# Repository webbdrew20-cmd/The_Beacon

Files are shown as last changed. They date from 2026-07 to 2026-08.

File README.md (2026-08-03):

# 📡 Project Beacon

> **An air-gapped, ultra-low-power emergency information server, long-range LoRa mesh communicator, and local weather station.**

---

## 💡 Why Project Beacon Was Built

In severe weather events, natural disasters, or power grid failures, centralized telecommunications are usually the first point of failure. When cell towers lose power and internet service drops, two vital lifelines disappear instantly: **access to information** (medical emergency guides, survival handbooks, repair manuals) and **the ability to communicate** with neighbors and loved ones.

**Project Beacon** was created to solve this problem by bringing both lifelines into a single, compact, off-grid appliance. Operating entirely on standard 5V USB power banks or small solar panels, Beacon creates an instant local Wi-Fi portal and long-range radio network—requiring **zero cellular service, zero internet connections, and zero external infrastructure.**

---

## 🎯 Target Use Cases & Scenarios

* 🌪️ **Natural Disasters & Severe Weather:** Deploy during hurricanes, tornadoes, floods, or winter storms when local cell towers suffer blackouts or tower congestion.
* 📻 **Emergency Community Mesh Communications:** Establish decentralized, long-range text messaging across miles between neighborhood nodes without relying on third-party cellular carriers or ISPs.
* 🏕️ **Off-Grid & Backcountry Expeditions:** Provide hikers, overlanders, or off-grid homesteads with offline maps, survival literature, and micro-climate forecasting where cell service doesn't exist.
* 🏥 **Offline Medical & Survival Reference Hub:** Host complete offline copies of Wikipedia, emergency medical guides, and technical manuals accessible from any smartphone, tablet, or laptop via a local captive Wi-Fi portal.

---

## 🚀 Motivation & Mission

I undertook this project to build a fully open-source, modular hardware appliance that proves what modern low-power microcontrollers are truly capable of. 

Rather than relying on expensive, power-hungry single-board computers or proprietary commercial gear, Project Beacon combines the high-compute RISC-V architecture of the **ESP32-P4** with specialized **ESP32-S3** auxiliary microcontrollers. By dividing the workload—allocating heavy ZIM database search indexing to the main P4 board, LoRa packet routing to a dedicated radio node, local media streaming to a secondary S3, and micro-climate barometric analysis to a compact sensor node—the system achieves high performance while pulling minimal power.

This repository contains everything needed to build your own Beacon node from scratch: open-source C++/ESP-IDF firmware, pin-by-pin hardware schematics, 3D-printable enclosure files (`.3mf`), and step-by-step flashing guides.

# The_Beacon
Low-power, 5V ESP32 off-grid survival appliance featuring 256GB offline Wikipedia, LoRa mesh messaging, and environmental weather sensing.
## 📦 Bill of Materials (BOM)

Project Beacon relies on a modular, multi-controller architecture to handle heavy offline data processing, long-range mesh networking, and environmental monitoring without internet access.

### 🧠 Processing & Controllers
| Component | Model / Variant | Qty | Function in Project Beacon |
| :--- | :--- | :---: | :--- |
| **Main Processing Node** | Waveshare ESP32-P4 Wi-Fi 6 Basic Kit | 1 | Primary server host (High-performance RISC-V compute, web hosting, offline database indexing) |
| **Entertainment** | ESP32-S3-WROOM-2 | 1 | Dedicated controller managing communication pipelines and local display UI |
|**Weather/Lora Nodes** | ESP32-S3 Super Mini | 2 | Ultra-compact controllers for remote sensor gathering and auxiliary radio endpoints |

### 💾 Storage & Data
| Component | Model / Variant | Qty | Function in Project Beacon |
| :--- | :--- | :---: | :--- |
| **MicroSD Module** | HW-125 SD Card Reader | 2 | SPI-based storage interface for hosting large offline ZIM databases (Wikipedia/Medical) and system logs |

### 📡 Wireless & Communication
| Component | Model / Variant | Qty | Function in Project Beacon |
| :--- | :--- | :---: | :--- |
| **LoRa Radio Transceiver** | Semtech SX1262 Module | 1 | Sub-GHz long-range off-grid mesh radio communication |

### 🌡️ Sensors & User Interface
| Component | Model / Variant | Qty | Function in Project Beacon |
| :--- | :--- | :---: | :--- |
| **Barometric Pressure Sensor** | BMP280 | 1 | Measures atmospheric pressure and precise ambient temperature over I2C |
| **Humidity & Temp Sensor** | HW-507 (DHT11 Module) | 1 | Digital ambient relative humidity and temperature monitoring |
| **Status Display** | 0.96" OLED (SSD1306 I2C) | 1 | 128x64 display showing live node status, signal strength, and environmental readings |

---

### 🔩 Recommended Hardware & Wiring Accessories
* **Storage:** 2x High-end MicroSD Cards (Class 10 / UHS-I, 32GB to 256GB formatted FAT32/exFAT depending on database size).
* **Power Supply:** 5V / 3A USB-C Power Bank or regulated DC step-down power rail.
* **Interconnects:** DuPont jumper wires (F-F, M-F) and solid copper core wire for custom breadboard/PCB routing.
* **Antenna:** 868MHz / 915MHz SMA antenna matched to your regional LoRa frequency.

## 🔌 Wiring & Assembly Instructions

> ⚠️ **CRITICAL WIRING RULES BEFORE POWERING ON:**
> 1. **Common Ground (GND):** Every microcontroller board and peripheral module **must share a single common ground connection** to ensure logic signals reference the same baseline voltage.
> 2. **UART TX/RX Crossover:** Always connect Transmit to Receive ($TX \rightarrow RX$) and Receive to Transmit ($RX \rightarrow TX$) between communicating microcontrollers.
> 3. **Logic Levels:** The SX1262 radio, BMP280, and hw507 operate on **3.3V logic**. Connecting 5V directly to their data or power pins will permanently damage the hardware.

---

### 1. Main Processing Node (Waveshare ESP32-P4)

The ESP32-P4 manages primary web hosting and routes data between nodes[cite: 2, 3].

#### 💾 MicroSD Card Module #1 (System & ZIM Storage)
Connect the primary HW-125 SD module over SPI[cite: 2]:

| HW-125 Pin | ESP32-P4 Pin | Signal Name | Notes |
| :--- | :--- | :--- | :--- |
| **VCC** | **5V** | Power Rail | Use 5V if using an onboard regulator on the HW-125 module |
| **GND** | **GND** | Common Ground | Required |
| **MISO** | **GPIO 52** | `BEACON_SD_MISO` | SPI Master In / Slave Out[cite: 2] |
| **MOSI** | **GPIO 51** | `BEACON_SD_MOSI` | SPI Master Out / Slave In[cite: 2] |
| **SCK** | **GPIO 31** | `BEACON_SD_SCK` | SPI Serial Clock[cite: 2] |
| **CS** | **GPIO 30** | `BEACON_SD_CS` | SPI Chip Select[cite: 2] |

#### 🔀 Inter-Board UART Serial Links
Connect the P4's hardware serial buses to the auxiliary controller nodes[cite: 2]:

| Target Node | P4 UART Bus | P4 Pin | Target Node Pin | Line Function |
| :--- | :--- | :--- | :--- | :--- |
| **LoRa Mesh Node** | `UART_LORA`[cite: 2] | **GPIO 22** (TX)[cite: 2] | **GPIO 8** (RX)[cite: 1] | P4 Transmits commands to LoRa |
| **LoRa Mesh Node** | `UART_LORA`[cite: 2] | **GPIO 23** (RX)[cite: 2] | **GPIO 9** (TX)[cite: 1] | P4 Receives mesh inbox data from LoRa |
| **Media Node (WROOM-2)** | `UART_WROOM2`[cite: 2] | **GPIO 21** (TX)[cite: 2] | **GPIO 19** (RX)[cite: 4] | P4 Transmits media requests |
| **Media Node (WROOM-2)** | `UART_WROOM2`[cite: 2] | **GPIO 20** (RX)[cite: 2] | **GPIO 20** (TX)[cite: 4] | P4 Receives media status updates |

---

### 2. LoRa Communication Node (ESP32-S3)

This node executes the `RadioLib` mesh firmware and maintains the wireless message queue[cite: 1].

#### 📡 Semtech SX1262 Transceiver (SPI)
Connect the LoRa module to the dedicated SPI controller[cite: 1]:

| SX1262 Pin | ESP32-S3 Pin | Signal Name | Notes |
| :--- | :--- | :--- | :--- |
| **VCC** | **3.3V** | Power | **DO NOT USE 5V** |
| **GND** | **GND** | Ground | Common Ground |
| **NSS / CS** | **GPIO 10** | `LORA_CS` | SPI Chip Select[cite: 1] |
| **SCK** | **GPIO 11** | `LORA_SCK` | SPI Clock[cite: 1] |
| **MOSI** | **GPIO 12** | `LORA_MOSI` | SPI Master Out / Slave In[cite: 1] |
| **MISO** | **GPIO 13** | `LORA_MISO` | SPI Master In / Slave Out[cite: 1] |
| **NRESET** | **GPIO 7** | `LORA_RST` | Hardware Reset[cite: 1] |
| **BUSY** | **GPIO 6** | `LORA_BUSY` | Radio Busy State Line[cite: 1] |
| **DIO1** | **GPIO 5** | `LORA_DIO1` | Hardware Interrupt Trigger (`onDio1`)[cite: 1] |

#### 🔗 Serial Link to P4 Node
| ESP32-S3 Pin | Direction | Waveshare P4 Pin | Notes |
| :--- | :---: | :--- | :--- |
| **GPIO 8** (`P4_UART_RX`)[cite: 1] | $\leftarrow$ | **GPIO 22** (P4 TX)[cite: 2] | Listens to P4 data requests |
| **GPIO 9** (`P4_UART_TX`)[cite: 1] | $\rightarrow$ | **GPIO 23** (P4 RX)[cite: 2] | Flushes inbox JSON to P4 |

---

### 3. Entertainment Node (ESP32-S3-WROOM-2)

Dedicated controller handling local audio and ROM file streaming[cite: 4, 5].

#### 💾 MicroSD Card Module #2 (Media Storage)
Connect the secondary HW-125 module to the WROOM-2 SPI bus[cite: 4]:

| HW-125 Pin | WROOM-2 Pin | Signal Name | Notes |
| :--- | :--- | :--- | :--- |
| **VCC** | **5V** | Power Rail | Power supply line |
| **GND** | **GND** | Ground | Common Ground |
| **MISO** | **GPIO 12** | `W2_SD_MISO` | SPI Master In / Slave Out[cite: 4] |
| **MOSI** | **GPIO 11** | `W2_SD_MOSI` | SPI Master Out / Slave In[cite: 4] |
| **SCK** | **GPIO 10** | `W2_SD_SCK` | SPI Serial Clock[cite: 4] |
| **CS** | **GPIO 9** | `W2_SD_CS` | SPI Chip Select[cite: 4] |

#### 🔗 Serial Link to P4 Node
| WROOM-2 Pin | Direction | Waveshare P4 Pin | Notes |
| :--- | :---: | :--- | :--- |
| **GPIO 19** (`UART_P4_RX`)[cite: 4] | $\leftarrow$ | **GPIO 21** (P4 TX)[cite: 2] | Listens to P4 HTTP portal |
| **GPIO 20** (`UART_P4_TX`)[cite: 4] | $\rightarrow$ | **GPIO 20** (P4 RX)[cite: 2] | Sends streaming status to P4 |

---

### 4. Weather Station Node (ESP32 Super Mini)

This standalone node uses separate I2C buses to manage its display and barometric pressure sensor, plus a digital input for humidity[cite: 6].

#### 🖥️ 0.96" OLED Display (SSD1306 - I2C Bus 0)
| SSD1306 Pin | ESP32 Super Mini Pin | Signal Name |
| :--- | :--- | :--- |
| **VCC** | **5v** | Power Rail |
| **GND** | **GND** | Common Ground |
| **SDA** | **GPIO 10** | `OLED_SDA`[cite: 6] |
| **SCL** | **GPIO 11** | `OLED_SCL`[cite: 6] |

#### 🌡️ BMP280 Barometric Pressure Sensor (I2C Bus 1)
| BMP280 Pin | ESP32 Super Mini Pin | Signal Name | Notes |
| :--- | :--- | :--- | :--- |
| **VCC** | **3.3V** | Power Rail | **3.3V only** |
| **GND** | **GND** | Common Ground | Common Ground |
| **SDA** | **GPIO 1** | `BMP_SDA`[cite: 6] | Secondary Wire instance (`I2CBMP`)[cite: 6] |
| **SCL** | **GPIO 2** | `BMP_SCL`[cite: 6] | Secondary Wire instance (`I2CBMP`)[cite: 6] |

#### 💧 HW-507 / DHT11 Temp & Humidity Sensor
| DHT11 Pin | ESP32 Super Mini Pin | Signal Name | Notes |
| :--- | :--- | :--- | :--- |
| **VCC** | **3.3V** | Power Rail | Power supply |
| **GND** | **GND** | Common Ground | Common Ground |
| **DATA** | **GPIO 3** | `DHTPIN`[cite: 6] | 1-Wire Digital Data Line[cite: 6] |

# 📡 Project Beacon: Off-Grid Hardware Stack

Project Beacon is a modular, multi-node offline server and mesh communication appliance. It combines a high-performance **ESP32-P4** primary server node with auxiliary **ESP32-S3** controllers for long-range LoRa messaging, local media delivery, and micro-climate sensing.

---

## 🔍 Step 1: Locate Your Board's COM Port (Windows Device Manager)

Before flashing firmware or opening a serial console, you need to identify which **COM Port** Windows assigned to your plugged-in ESP32 board.

1. Connect your ESP32 board to your computer using a **data-capable USB-C cable**.
2. Open **Device Manager**:
   * Press `Win + X` on your keyboard and select **Device Manager**.
   * *Alternative:* Press `Win + R`, type `devmgmt.msc`, and hit **Enter**.
3. Expand the **Ports (COM & LPT)** section.
4. Look for an entry such as:
   * `Silicon Labs CP210x USB to UART Bridge (COMx)`
   * `USB-SERIAL CH340 (COMx)`
   * `USB Serial Device (COMx)` *(Standard ESP32 native USB-CDC driver)*
5. **How to verify your port:** Unplug your USB cable and plug it back in. The entry that disappears and reappears is your target port (e.g., `COM3`, `COM5`, `COM12`).

---

## 🛠️ Step 2: Build, Flash & Monitor with ESP-IDF v5.5

The main processing node and entertainment node run on **ESP-IDF v5.5** to support multi-threading, custom partition tables, and high-performance PSRAM access[cite: 3, 5].

### Environment Prerequisites
* Open the **ESP-IDF 5.5 CMD** terminal (or **ESP-IDF 5.5 PowerShell**) installed on your machine.
* Ensure `idf.py` is available in your PATH environment.

---

### Node 1: Waveshare ESP32-P4 (Main Server Node)
* **Directory:** `/p4_beacon_project`
* **Entry Point:** `main/beacon_main.c`[cite: 3]

1. **Navigate to the project directory:**
   ```cmd
   cd path\to\Project-Beacon\p4_beacon_project

## 🖨️ 3D Printing & Post-Processing Guide

Pre-configured printable model files for the Project Beacon enclosure, internal brackets, and mounting plates are provided in the repository as **`.3mf`** files.

---

### 🧵 Material & Support Recommendations

* **Primary Chassis Filament:** **PA6 (Nylon 6)** is strongly recommended for its high heat deflection temperature, extreme impact strength, and rugged outdoor durability.
* **Support Interface Filament:** **ABS** (or ABS-GF/CF).

> 💡 **Pro-Tip (Dual-Material / AMS / MMU Printing):** 
> When printing the main body in **PA6**, set **ABS as your Support Interface material**. PA6 and ABS do not bond chemically during extrusion. Using ABS for interface layers allows solid support structures to snap off effortlessly, leaving a clean, glass-smooth surface without scarring your print.

---

### 🛠️ Hardware Post-Processing & Hole Preparation

Due to normal FDM thermal contraction and inner-wall extrusion squish, printed holes will be slightly tight straight off the build plate.

1. **Drill Before Fastening:** Always chase/clean out every screw hole with a drill bit sized for the bolts( around -.5mm of actual size).

# 📡 Beacon System — Storage Layouts & Content Setup Guide

This master repository guide details the root-level folder structures for both the **ESP32-P4** and **ESP32-S3 WROOM-2** hardware targets, along with step-by-step instructions for extracting Kiwix `.zim` archives for offline hosting.

---

## 📂 1. ESP32-P4 and s3 wroom2 Storage Layout (

```text
p4/ (Storage Root)
├── www/                       # Core Web UI & Application Framework
│   ├── index.html             # Primary landing page
│   └── sites.html             # System navigation index
├── content/                   # Raw media archives, audio files, and downloads
├── library/                   # Offline books, reference guides, and technical manuals
│   └── [book-folder]/
│       └── index.html
└── infoweb/                   # Self-contained offline websites (Kiwix extractions)
    └── [unpacked-site]/
        └── index.html

---

```text
s3wroom2/ (SD Card Root)
├── games/                     # Game emulation root folder
│   ├── ejs/                   # EmulatorJS core engine files
│   │   └── data/              # Emulator assets (requires loader.js)
│   └── roms/                  # Game ROM files (.gb)
├── music/                     # Audio storage directory (.mp3 files)
└── www/                       # Core Web UI framework
    ├── index.html             # Main system landing page
    ├── sites.html             # System menu/navigation index
    ├── music.html             # HTML5 audio player interface
    ├── games.html             # Game library & selection portal
    └── play.html              # EmulatorJS launch & canvas window

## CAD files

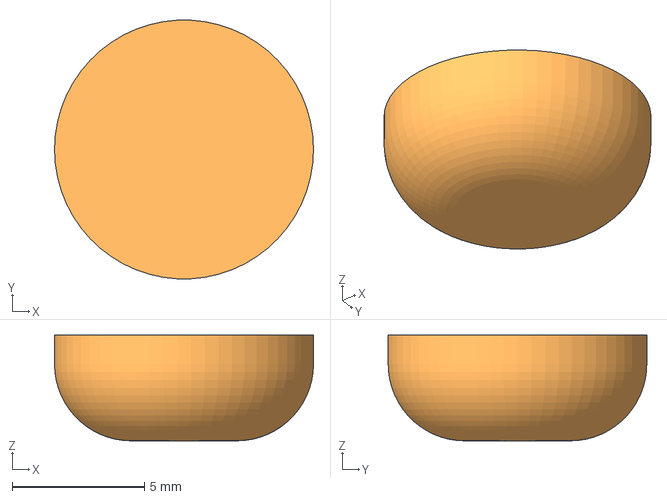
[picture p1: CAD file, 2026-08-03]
feet (1).3mf
9.80 x 9.79 x 4.00 mm

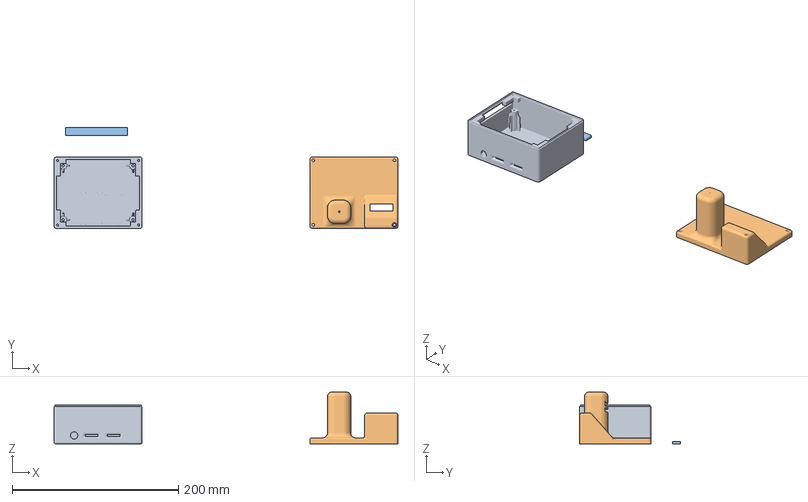
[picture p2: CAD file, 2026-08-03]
case.3mf
413.3 x 121.5 x 62.2 mm

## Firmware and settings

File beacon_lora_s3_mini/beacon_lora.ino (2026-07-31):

#include <SPI.h>
#include <RadioLib.h>
#include <FS.h>
#include <LittleFS.h>
#include <Preferences.h>
#include "mesh_types.h"


#define LORA_CS    10
#define LORA_SCK   11
#define LORA_MOSI  12
#define LORA_MISO  13
#define LORA_RST   7
#define LORA_BUSY  6
#define LORA_DIO1  5

#define P4_UART_RX 8      
#define P4_UART_TX 9      
#define P4_BAUD    115200

#define LORA_FREQ_MHZ   915.0f   
#define LORA_BW_KHZ     125.0f
#define LORA_SF         9       
#define LORA_CR         7       
#define LORA_POWER_DBM  20
#define LORA_PREAMBLE   8

#define MESH_TTL_DEFAULT   3     
#define SEEN_CACHE_SIZE    32

#define INBOX_PATH         "/inbox.jsonl"
#define INBOX_MAX_BYTES    (200*1024)

#define HEARTBEAT_MS 3000


SX1262 radio = new Module(LORA_CS, LORA_DIO1, LORA_RST, LORA_BUSY);

volatile bool rxFlag = false;
void onDio1() { rxFlag = true; }


Preferences prefs;
uint32_t myNodeId = 0;
char myName[24] = "";

uint32_t seenIds[SEEN_CACHE_SIZE];
int seenHead = 0;

bool inboxHasData = false;
bool g_radioOK = false;
unsigned long lastHb = 0;
unsigned long lastFetchMs = 0;
unsigned long lastStatusPrint = 0;


static void putU32(uint8_t *p, uint32_t v) {
  p[0] = v; p[1] = v >> 8; p[2] = v >> 16; p[3] = v >> 24;
}
static uint32_t getU32(const uint8_t *p) {
  return (uint32_t)p[0] | ((uint32_t)p[1] << 8) | ((uint32_t)p[2] << 16) | ((uint32_t)p[3] << 24);
}
static int packMesh(const MeshMsg &m, uint8_t *out) {
  putU32(out + 0, m.id); putU32(out + 4, m.from); putU32(out + 8, m.to);
  out[12] = m.ttl; out[13] = m.ch; out[14] = m.textLen;
  memcpy(out + 15, m.text, m.textLen);
  return 15 + m.textLen;
}
static bool unpackMesh(const uint8_t *in, size_t len, MeshMsg &m) {
  if (len < 15) return false;
  m.id = getU32(in + 0); m.from = getU32(in + 4); m.to = getU32(in + 8);
  m.ttl = in[12]; m.ch = in[13]; m.textLen = in[14];
  if ((size_t)(15 + m.textLen) > len || m.textLen > MAX_TEXT_LEN) return false;
  memcpy(m.text, in + 15, m.textLen);
  m.text[m.textLen] = 0;
  return true;
}

static bool seen(uint32_t id) {
  for (int i = 0; i < SEEN_CACHE_SIZE; i++) if (seenIds[i] == id) return true;
  return false;
}
static void markSeen(uint32_t id) {
  seenIds[seenHead] = id;
  seenHead = (seenHead + 1) % SEEN_CACHE_SIZE;
}


static void jesc(const char *in, char *out, size_t cap) {
  size_t o = 0;
  for (; *in && o + 2 < cap; in++) {
    unsigned char c = (unsigned char)*in;
    if (c == '"' || c == '\\') { out[o++] = '\\'; out[o++] = c; }
    else if (c < 0x20) out[o++] = ' ';
    else out[o++] = c;
  }
  out[o] = 0;
}
static bool jsonStr(const char *json, const char *key, char *out, size_t cap) {
  char pat[32]; snprintf(pat, sizeof(pat), "\"%s\":\"", key);
  const char *p = strstr(json, pat);
  if (!p) return false;
  p += strlen(pat);
  size_t o = 0;
  while (*p && *p != '"' && o < cap - 1) {
    if (*p == '\\' && p[1]) p++;
    out[o++] = *p++;
  }
  out[o] = 0;
  return true;
}
static bool jsonNum(const char *json, const char *key, long *out) {
  char pat[32]; snprintf(pat, sizeof(pat), "\"%s\":", key);
  const char *p = strstr(json, pat);
  if (!p) return false;
  *out = atol(p + strlen(pat));
  return true;
}


static void inboxAppendStr(const char *fromStr, uint8_t ch, const char *text) {
  File f = LittleFS.open(INBOX_PATH, FILE_APPEND);
  if (!f) return;
  if (f.size() > INBOX_MAX_BYTES) {   
    f.close();
    File in = LittleFS.open(INBOX_PATH, "r");
    String rest = in ? in.readString() : "";
    if (in) in.close();
    rest = rest.substring(rest.length() / 2);
    int nl = rest.indexOf('\n');
    if (nl > 0) rest = rest.substring(nl + 1);
    File out = LittleFS.open(INBOX_PATH, "w");
    if (out) { out.print(rest); out.close(); }
    f = LittleFS.open(INBOX_PATH, FILE_APPEND);
    if (!f) return;
  }
  char esc[MAX_TEXT_LEN * 2 + 8];
  jesc(text, esc, sizeof(esc));
  char fesc[28];
  jesc(fromStr, fesc, sizeof(fesc));
  f.printf("{\"from\":\"%s\",\"ch\":%u,\"text\":\"%s\"}\n", fesc, ch, esc);
  f.close();
  inboxHasData = true;
}

static void inboxAppend(uint32_t from, uint8_t ch, const char *text) {
  char fs[12];
  snprintf(fs, sizeof(fs), "%08x", (unsigned)from);
  inboxAppendStr(fs, ch, text);
}

static void inboxSendToP4() {
  File f = LittleFS.open(INBOX_PATH, "r");
  if (!f || f.size() == 0) { if (f) f.close(); return; }
  Serial1.print("{\"type\":\"msgs\",\"items\":[");
  bool first = true;
  while (f.available()) {
    String line = f.readStringUntil('\n');
    if (line.length() < 2) continue;
    if (!first) Serial1.print(',');
    Serial1.print(line);
    first = false;
  }
  Serial1.print("]}\n");
  f.close();
}

static void inboxClear() {
  File f = LittleFS.open(INBOX_PATH, "w");   // truncate
  if (f) f.close();
  inboxHasData = false;
}


static void handleReceivedPacket(const uint8_t *buf, size_t len) {
  MeshMsg m;
  if (!unpackMesh(buf, len, m)) return;
  if (seen(m.id)) return;
  markSeen(m.id);

  bool forMe = (m.to == 0 || m.to == myNodeId);
  if (forMe) inboxAppend(m.from, m.ch, m.text);

 
  bool shouldRelay = (m.to != myNodeId) && (m.ttl > 0);
  if (shouldRelay) {
    m.ttl--;
    delay(random(50, 250));   // jitter — reduces collision storms on relay
    uint8_t out[15 + MAX_TEXT_LEN];
    int n = packMesh(m, out);
    radio.transmit(out, n);
    radio.startReceive();
  }
}


static void sendMeshMessage(const char *toStr, uint8_t ch, const char *text) {
  MeshMsg m;
  m.id = (uint32_t)random(1, 0x7fffffff);
  m.from = myNodeId;
  m.to = (toStr && toStr[0]) ? strtoul(toStr, NULL, 16) : 0;
  m.ttl = MESH_TTL_DEFAULT;
  m.ch = ch;
  m.textLen = (uint8_t)strnlen(text, MAX_TEXT_LEN);
  memcpy(m.text, text, m.textLen);

  markSeen(m.id);   // don't re-process our own message if it floods back

  if (!g_radioOK) {
    inboxAppendStr("system", ch,
      "Radio offline - message NOT sent over the air. Check wiring.");
    return;
  }

  uint8_t out[15 + MAX_TEXT_LEN];
  int n = packMesh(m, out);
  int st = radio.transmit(out, n);
  radio.startReceive();
  if (st != RADIOLIB_ERR_NONE) {
    char eb[64];
    snprintf(eb, sizeof(eb), "Radio TX failed (code %d)", st);
    inboxAppendStr("system", ch, eb);
    Serial.println(eb);
  } else {
    Serial.printf("TX ok: %d bytes over the air\n", n);
  }
}


static void handleP4Line(const char *line) {
  if (strstr(line, "\"fetch\"")) {
    lastFetchMs = millis();
    if (inboxHasData) inboxSendToP4();
  } else if (strstr(line, "\"ack\"")) {
    inboxClear();
  } else if (strstr(line, "\"send\"")) {
    char to[24] = "", text[MAX_TEXT_LEN + 1] = "";
    long ch = 0;
    jsonStr(line, "to", to, sizeof(to));
    jsonStr(line, "text", text, sizeof(text));
    jsonNum(line, "ch", &ch);
    sendMeshMessage(to, (uint8_t)ch, text);

   
    if (strncmp(text, "/echo", 5) == 0) {
      const char *rest = text + 5;
      while (*rest == ' ') rest++;
      char reply[MAX_TEXT_LEN + 16];
      if (*rest)
        snprintf(reply, sizeof(reply), "Echo: %s", rest);
      else
        snprintf(reply, sizeof(reply), "Echo OK - inbound path works");
      char myid[12];
      snprintf(myid, sizeof(myid), "%08x", (unsigned)myNodeId);
      inboxAppendStr(myid, (uint8_t)ch, reply);
    }
  } else if (strstr(line, "set_name")) {
    char n[24];
    if (jsonStr(line, "name", n, sizeof(n))) {
      strlcpy(myName, n, sizeof(myName));
      prefs.putString("name", myName);
    }
  }
}


void setup() {
  Serial.begin(115200);
 
  unsigned long t0 = millis();
  while (!Serial && millis() - t0 < 3000) delay(10);
  delay(200);
  Serial.println("=== Beacon LoRa node booting ===");

  Serial1.begin(P4_BAUD, SERIAL_8N1, P4_UART_RX, P4_UART_TX);

  myNodeId = (uint32_t)(ESP.getEfuseMac() & 0xFFFFFFFF);
  prefs.begin("beacon", false);
  String savedName = prefs.getString("name", "");
  strlcpy(myName, savedName.c_str(), sizeof(myName));
  Serial.printf("Node ID: %08x  Name: %s\n", (unsigned)myNodeId, myName[0] ? myName : "(unset)");

  if (!LittleFS.begin(true)) {
    Serial.println("LittleFS mount failed — inbox will not persist across reboots");
  }
  File initF = LittleFS.open(INBOX_PATH, "r");
  inboxHasData = initF && initF.size() > 0;
  if (initF) initF.close();

  SPI.begin(LORA_SCK, LORA_MISO, LORA_MOSI, LORA_CS);
  int state = radio.begin(LORA_FREQ_MHZ, LORA_BW_KHZ, LORA_SF, LORA_CR,
                          RADIOLIB_SX126X_SYNC_WORD_PRIVATE, LORA_POWER_DBM,
                          LORA_PREAMBLE);
  g_radioOK = (state == RADIOLIB_ERR_NONE);
  if (!g_radioOK) {
    Serial.printf("Radio init failed, code %d — check wiring/pins\n", state);
  } else {
    radio.setDio1Action(onDio1);
    radio.startReceive();
    Serial.println("Radio listening");
  }

  randomSeed(esp_random());

 
  char myid[12];
  snprintf(myid, sizeof(myid), "%08x", (unsigned)myNodeId);
  char boot[MAX_TEXT_LEN];
  snprintf(boot, sizeof(boot),
           "Node %s online. Radio: %s. Storage: %s.%s%s",
           myid,
           g_radioOK ? "OK" : "FAILED - check wiring",
           LittleFS.begin(false) ? "OK" : "FAILED",
           myName[0] ? " Name: " : "",
           myName[0] ? myName : "");
  inboxAppendStr(myid, 0, boot);
  Serial.println(boot);
  Serial.println("Waiting for P4 fetch (every ~3s) to deliver boot message...");
}


void loop() {
 
  if (rxFlag) {
    rxFlag = false;
    uint8_t buf[15 + MAX_TEXT_LEN];
    int len = radio.getPacketLength();
    if (len > 0 && (size_t)len <= sizeof(buf)) {
      int state = radio.readData(buf, len);
      if (state == RADIOLIB_ERR_NONE) handleReceivedPacket(buf, len);
    }
    radio.startReceive();
  }

  
  static char line[300];
  static int llen = 0;
  while (Serial1.available()) {
    char c = (char)Serial1.read();
    if (c == '\n' || c == '\r') {
      if (llen > 0) { line[llen] = 0; handleP4Line(line); llen = 0; }
    } else if (llen < (int)sizeof(line) - 1) {
      line[llen++] = c;
    } else {
      llen = 0;
    }
  }

  
  unsigned long now = millis();
  if (now - lastHb >= HEARTBEAT_MS) {
    lastHb = now;
    if (!inboxHasData) Serial1.print("{\"type\":\"hb\"}\n");
  }

  
  if (now - lastStatusPrint >= 5000) {
    lastStatusPrint = now;
    Serial.printf("alive %lus | radio %s | inbox %s | P4 fetch: ",
                  now / 1000, g_radioOK ? "OK" : "FAIL",
                  inboxHasData ? "pending" : "empty");
    if (lastFetchMs == 0) Serial.println("never (check UART to P4)");
    else Serial.printf("%lus ago\n", (now - lastFetchMs) / 1000);
  }
}

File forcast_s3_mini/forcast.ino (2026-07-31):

#include <Wire.h>
#include <Adafruit_Sensor.h>
#include <Adafruit_BMP280.h>
#include <DHT.h>
#include <Adafruit_GFX.h>
#include <Adafruit_SSD1306.h>
#define OLED_SDA 10
#define OLED_SCL 11
#define BMP_SDA 1
#define BMP_SCL 2
#define DHTPIN 3
#define DHTTYPE DHT11
TwoWire I2CBMP = TwoWire(1); 
#define SCREEN_WIDTH 128
#define SCREEN_HEIGHT 64
Adafruit_SSD1306 display(SCREEN_WIDTH, SCREEN_HEIGHT, &Wire, -1);
Adafruit_BMP280 bmp(&I2CBMP);
DHT dht(DHTPIN, DHTTYPE);
float pressureHistory[6]; // Holds 6 readings (1 hour of data at 10 min intervals)
int historyIndex = 0;
bool isCalibrated = false; 
unsigned long lastReadingTime = 0;
const unsigned long READING_INTERVAL = 600000; 

void setup() {
  Serial.begin(115200);

  
  Wire.begin(OLED_SDA, OLED_SCL);
  if(!display.begin(SSD1306_SWITCHCAPVCC, 0x3C)) {
    Serial.println(F("SSD1306 OLED failed"));
    while(1);
  }
  display.clearDisplay();
  display.setTextColor(WHITE);

  
  I2CBMP.begin(BMP_SDA, BMP_SCL);
  if (!bmp.begin(0x76)) { // 0x76 is standard, try 0x77 if it fails
    Serial.println(F("BMP280 failed"));
    while(1);
  }

  
  dht.begin();

  
  float startPressure = bmp.readPressure() / 100.0F; // Convert Pa to hPa
  for (int i = 0; i < 6; i++) {
    pressureHistory[i] = startPressure;
  }
  
  updateScreen("Calibrating...", startPressure, dht.readTemperature(), dht.readHumidity());
}

void loop() {
  unsigned long currentMillis = millis();

 
  if (currentMillis - lastReadingTime >= READING_INTERVAL) {
    lastReadingTime = currentMillis;

    
    float currentTempC = dht.readTemperature();
    float currentHum = dht.readHumidity();
    float currentPressure = bmp.readPressure() / 100.0F; 

    
    float pastPressure = pressureHistory[historyIndex];
    float trend = currentPressure - pastPressure; 

    
    pressureHistory[historyIndex] = currentPressure;
    historyIndex++;
    if (historyIndex >= 6) {
      historyIndex = 0;
      isCalibrated = true; 
    }

    
    String forecast = generateForecast(trend, currentPressure, currentTempC, currentHum);
    
    if (!isCalibrated) {
      forecast = "Gathering Data...";
    }

    
    updateScreen(forecast, currentPressure, currentTempC, currentHum);
  }
}

String generateForecast(float trend, float pressure, float temp, float humidity) {
  
  if (trend <= -1.5) {
    if (temp <= 0.0 && humidity > 70) return "SNOW STORM!";
    if (humidity > 70) return "HEAVY STORM!";
    return "HIGH WINDS";
  } 
  
  else if (trend < -0.5) {
    if (temp <= 0.0) return "LIGHT SNOW";
    return "RAIN LIKELY";
  } 
  
  else if (trend >= 0.5) {
    return "CLEARING UP";
  } 
  
  else {
    if (pressure > 1015.0) return "CLEAR / SUNNY";
    return "CLOUDY / STEADY";
  }
}

void updateScreen(String forecast, float pressure, float temp, float hum) {
  display.clearDisplay();
  
 
  display.setTextSize(1);
  display.setCursor(0, 0);
  display.println("FORECAST (6-12HR):");
  display.setTextSize(2);
  display.println(forecast);

 
  display.setTextSize(1);
  display.setCursor(0, 35);
  display.print("Temp: ");
  display.print(temp);
  display.println(" C");
  
  display.print("Hum:  ");
  display.print(hum);
  display.println(" %");

  display.print("Pres: ");
  display.print(pressure);
  display.println(" hPa");

  display.display();
}
